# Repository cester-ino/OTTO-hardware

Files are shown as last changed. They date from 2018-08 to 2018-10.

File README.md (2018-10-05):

## OTTO-project
Hardware prototype for the [OTTO Synthesizer by Topisani](https://github.com/topisani/OTTO "OTTO Synthesizer by Topisani")

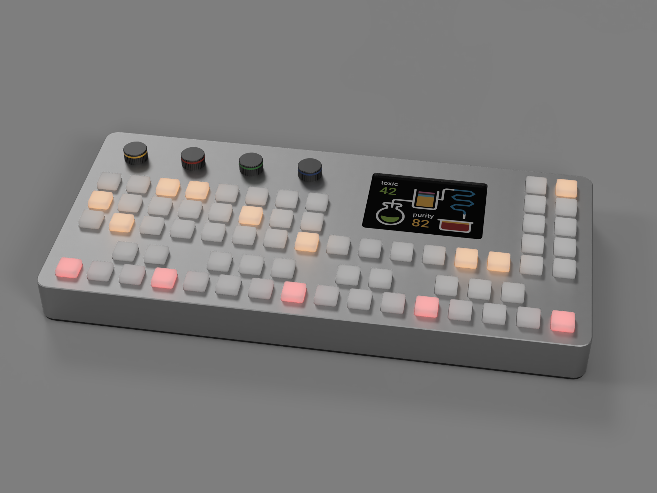
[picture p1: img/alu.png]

*10x10 silicone buttons with led backlight*

Main features

#### Mainboard
- ILI9341 based TFT 2.8" TFT screen.
- 4 low profile clickable encoders
- 40 function keys
- STM32F103VET6 mcu
- Raspberry GPIO connector
- connects to all the various boards
- expansion headers

#### Power board
- 2A 5-16V DC input & 500mah micro usb input
- [MAX8903A](https://datasheets.maximintegrated.com/en/ds/MAX8903-MAX8903Y.pdf "MAX8903A") 1s Lipo charger IC with path management
- 5V 2A DC-DC boost converter ([TPS61090](http://www.ti.com/lit/ds/symlink/tps61090.pdf "TPS61090")) & 3V3 700mah LDO ([XC6210](https://www.torexsemi.com/file/xc6210/XC6210.pdf "XC6210"))
- [MAX17048](https://datasheets.maximintegrated.com/en/ds/MAX17048-MAX17049.pdf "MAX17048") 1s lipo fuel gauge, connected via i2c to the raspberry
- [pi_power](https://github.com/craic/pi_power "pi_power") circuit for monitoring and control boot and shutdown routine

#### Audio Board
- SGTL5000 Audio Codec
- Electret microphone amp circuit
- LM4860 speaker amplifier
- 1 TRS jack line IN
- 1 TRS jack line OUT
- 1 Headphone IN

#### Keyboard
- 2 octaves keyboard with 16 keys bottom row
- expansion headers
- 16 addressable rgb leds

those specs refer to the tactile buttons version, but a led backlight button version is in the works too.

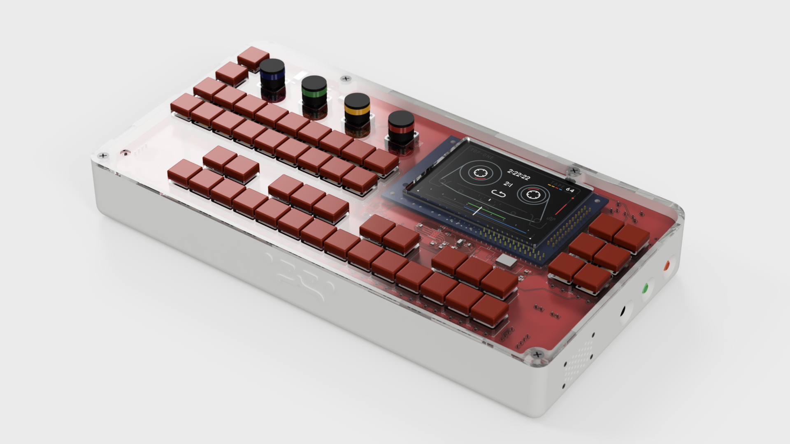
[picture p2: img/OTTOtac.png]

*one of the first design iteration*

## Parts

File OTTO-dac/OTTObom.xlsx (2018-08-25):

Refs | Value | Footprint | Quantity | MFR | MPN | SPR | SPN | Column1
SW55 | ON_OFF_SWITCH | Button_Switch_THT:SK-12E12-G5 | 1 |  |  | lcsc | C136720
SW8;SW7;SW11;SW12;SW15;SW19;SW23;SW27;SW30;SW34;SW36;SW37;SW39;SW43;SW47;SW50;SW18;SW22;SW26;SW33;SW35;SW38;SW42;SW46;SW3;SW4;SW2;SW1;SW5;SW6;SW10;SW14;SW17;SW9;SW13;SW16;SW49;SW45;SW41;SW40;SW44;SW48;SW31;SW28;SW24;SW29;SW25;SW21;SW20;SW32 | SW_Push | Button_Switch_THT:Tactile_Switch_12x12x7.3_mm | 50 | - | - | lcsc | -
MK1 | Microphone | CMA-4544PF-W:CMA-4544PF-W | 1 | - | - | lcsc | C241681 (https://lcsc.com/product-detail/Others_INGHAi-GMI9750UP-2C44DB_C241681.html)
C22 | 0.01uF | Capacitor_SMD:C_0805_2012Metric | 1 | - | - | lcsc | C83170 (https://lcsc.com/product-detail/Multilayer-Ceramic-Capacitors-MLCC-SMD-SMT_10nF-103-10-50V_C83170.html)
C7;C11;C8;C9;C10;C13;C1;C6;C5;C21 | 0.1uF | Capacitor_SMD:C_0805_2012Metric | 10 | - | - | lcsc | C29926 (https://lcsc.com/product-detail/Multilayer-Ceramic-Capacitors-MLCC-SMD-SMT_100nF-104-5-50V_C29926.html) | V
C24 | 100pF | Capacitor_SMD:C_0805_2012Metric | 1 | - | - | lcsc | C107140 (https://lcsc.com/product-detail/Multilayer-Ceramic-Capacitors-MLCC-SMD-SMT_100pF-101-10-50V_C107140.html)
C12 | 10uF | Capacitor_SMD:C_0805_2012Metric | 1 | - | - | lcsc | C48181 (https://lcsc.com/product-detail/Multilayer-Ceramic-Capacitors-MLCC-SMD-SMT_10uF-106-20-25V_C48181.html)
C2;C23 | 1uF | Capacitor_SMD:C_0805_2012Metric | 2 | - | - | lcsc | C89378 (https://lcsc.com/product-detail/Multilayer-Ceramic-Capacitors-MLCC-SMD-SMT_1uF-105-20-25V_C89378.html)
C3;C4 | 22pF | Capacitor_SMD:C_0805_2012Metric | 2 | - | - | lcsc | C38143 (https://lcsc.com/product-detail/Multilayer-Ceramic-Capacitors-MLCC-SMD-SMT_22pF-220-5-50V_C38143.html)
C14 | 22uF | Capacitor_SMD:C_0805_2012Metric | 1 | - | - | lcsc | C89572 (https://lcsc.com/product-detail/Multilayer-Ceramic-Capacitors-MLCC-SMD-SMT_22uF-226-20-10V_C89572.html)
C19;C20 | 0.1uf | Capacitor_Tantalum_SMD:CP_EIA-2012-12_Kemet-R | 2 | - | - | lcsc | C154088
C18 | 1uf | Capacitor_Tantalum_SMD:CP_EIA-2012-12_Kemet-R | 1 | - | - | lcsc | C116269 (https://lcsc.com/product-detail/Tantalum-Capacitors_KEMET_T491A105K016AT_1uF-105-10-16V_C116269.html)
C16;C17 | 220uf | Capacitor_Tantalum_SMD:CP_EIA-2012-12_Kemet-R | 2 | - | - | lcsc | C7200
C15 | 22uF | Capacitor_Tantalum_SMD:CP_EIA-2012-12_Kemet-R | 1 | - | - | lcsc | C117031 (https://lcsc.com/product-detail/Tantalum-Capacitors_KEMET_T491B226M010AT_22uF-226-20-10V_C117031.html)
J10 | Conn_01x04_Male | Connector_JST:JST_SH_SM04B-SRSS-TB_1x04-1MP_P1.00mm_Horizontal | 1 | - | - | lcsc | C160404
J6 | Speaker | Connector_JST:JST_XH_B02B-XH-A_1x02_P2.50mm_Vertical | 1 | JST | XH-B02B | lcsc | C20079 (https://lcsc.com/product-detail/XH-Connectors_XH-2A-2P-pitch2-5mm-Straight-line_C20079.html)
J3 | battery | Connector_JST:JST_XH_B02B-XH-A_1x02_P2.50mm_Vertical | 1 | JST | XH-B02B | lcsc | C20079 (https://lcsc.com/product-detail/XH-Connectors_XH-2A-2P-pitch2-5mm-Straight-line_C20079.html)
J1 | USB | Connector_PinHeader_2.54mm:PinHeader_1x04_P2.54mm_Vertical | 1 | - | 1x04 pin header | lcsc | C124378 (https://lcsc.com/product-detail/Male-Header_Shenzhen-Cancome-Headers-Pins-1-4P-2-54mm-Straight-line_C124378.html)
J4 | audio | Connector_PinHeader_2.54mm:PinHeader_1x04_P2.54mm_Vertical | 1 | - | 1x04 pin header | lcsc | C124378 (https://lcsc.com/product-detail/Male-Header_Shenzhen-Cancome-Headers-Pins-1-4P-2-54mm-Straight-line_C124378.html)
J8 | gpio_exp1 | Connector_PinHeader_2.54mm:PinHeader_2x20_P2.54mm_Vertical | 1 | 2x20 long pin header | - | lcsc | C124383 (https://lcsc.com/product-detail/Male-Header_Shenzhen-Cancome-Headers-Pins-2-20P-2-54mm-Straight-line_C124383.html)
J7 | gpio_exp2 | Connector_PinHeader_2.54mm:PinHeader_2x20_P2.54mm_Vertical | 1 | 2x20 pin header | - | lcsc | C124383 (https://lcsc.com/product-detail/Male-Header_Shenzhen-Cancome-Headers-Pins-2-20P-2-54mm-Straight-line_C124383.html)
J2 | USB_B_Micro | Connector_USB:USB_Micro-B_Molex-105017-0001 | 1 | Molex | 105017-0001 | lcsc | C136000 (https://lcsc.com/product-detail/Micro-USB-Connectors_MOLEX_105017-0001_105017-0001_C136000.html)
Y1 | 16mhz | Crystal:Crystal_SMD_Abracon_ABM3-2Pin_5.0x3.2mm | 1 | - | ABM3-16.000MHZ-D2Y-T | lcsc | C112572 (https://lcsc.com/product-detail/SMD-Crystals_YSX530GA-16MHZ-20PF-10PPM-40-85_C112572.html)
D58 | SS34 | Diode_SMD:D_SMC | 1 | - | SS34 | lcsc | C13763 (https://lcsc.com/product-detail/Schottky-Barrier-Diodes-SBD_Jiangsu-Yutai-Elec-SS34_C13763.html)
D9;D8;D12;D13;D16;D20;D24;D28;D31;D35;D37;D38;D40;D44;D48;D51;D19;D23;D27;D34;D36;D39;D43;D47;D4;D5;D3;D2;D6;D7;D11;D15;D18;D10;D14;D17;D50;D46;D42;D41;D45;D49;D32;D29;D25;D30;D26;D22;D21;D33;D52;D53;D54;D55 | 1N4148 | Diode_SMD:D_SOD-123v | 54 | - | 1N4148W-E3-18 | lcsc | C129216 (https://lcsc.com/product-detail/Switching-Diode_1N4148W_C129216.html)
U7 | TJCTM24028-SPI | Display:TJCTM24028-SPI | 1 | - | - | lcsc | -
L1 | 22uH | Inductor_SMD:L_7.3x7.3_H4.5 | 1 | Epcos |  | lcsc | C181754
D1 | LED | LED_SMD:LED_0805_2012Metric | 1 | - | HSMW-C170-U0000 | lcsc | C34499 (https://lcsc.com/product-detail/Light-Emitting-Diodes-LED_white-0805_C34499.html)
D57 | LEDG | LED_SMD:LED_0805_2012Metric | 1 | - | HSMQ-C170-T0000 | lcsc | C74344 (https://lcsc.com/product-detail/Light-Emitting-Diodes-LED_0805_C74344.html)
D56 | LEDR | LED_SMD:LED_0805_2012Metric | 1 | - | HSMC-C170-T0000 | lcsc | C131250 (https://lcsc.com/product-detail/Infrared-IR-LEDs_Everlight-Elec-IR17-21C-TR8_C131250.html)
D59;D60;D61;D62;D63 | LED | LED_SMD:LED_0805_2012Metric | 5 | - | HSMW-C170-U0000 | lcsc | C34499 (https://lcsc.com/product-detail/Light-Emitting-Diodes-LED_white-0805_C34499.html)
IC2 | LM3914 | Package_LCC:PLCC-20 | 1 | - | LM3914VX/NOPB | lcsc | C9408 (https://lcsc.com/product-detail/LED-Drivers_TI_LM3914N-1-NOPB_LM3914N-1-NOPB_C9408.html)
U1 | ATMEGA32U4-AU | Package_QFP:TQFP-44-1EP_10x10mm_P0.8mm_EP4.5x4.5mm | 1 | - | ATMEGA32U4-AU | lcsc | 556-ATMEGA32U4-AU
IC1 | 74HC125 | Package_SO:SOIC-14_3.9x8.7mm_P1.27mm | 1 | - | SN74HC125DR | lcsc | 595-SN74HC125DR
U6 | LM4860 | Package_SO:SOIC-16_3.9x9.9mm_P1.27mm | 1 | - | LM4860MX/NOPB | lcsc | -
U2 | MCP602 | Package_SO:SOIC-8_3.9x4.9mm_P1.27mm | 1 | - | MCP6022T-I/SN | lcsc | -
U3 | TP4056 | Package_SO:Texas_HTSOP-8-1EP_3.9x4.9mm_P1.27mm_EP2.95x4.9mm_Mask2.4x3.1mm_ThermalVias | 1 | - | TP4056 SOP-8 | lcsc | C16581 (https://lcsc.com/product-detail/PMIC-Battery-Management_TP4056_C16581.html)
U4 | FS312F-G | Package_TO_SOT_SMD:SOT-23-6 | 1 | - | FS312F-G SOT-23 | lcsc | C82736 (https://lcsc.com/product-detail/Battery-Protection-ICs_FS312F-G_C82736.html)
U5 | MT3608 | Package_TO_SOT_SMD:SOT-23-6 | 1 | - | MT3608 SOT-23 | lcsc | C84817 (https://lcsc.com/product-detail/DC-DC-Converters_MT3608_C84817.html)
M1 | FS8205 | Package_TO_SOT_SMD:SOT-23-6_Handsoldering | 1 | - | FS8205 SOT-23 | lcsc | C94488 (https://lcsc.com/product-detail/MOSFET_RU8205C6_C94488.html)
U8 | MAX4466 | Package_TO_SOT_SMD:SOT-353_SC-70-5 | 1 | - | - | lcsc | -
Q1 | 2N7000 | Package_TO_SOT_THT:TO-92_Inline | 1 | - | - | lcsc | C232838
RV1 | 10K | Potentiometer_SMD:Potentiometer_Vishay_TS53YJ_Vertical | 1 | - | TS53YJ103MR10 | lcsc | C118956 (https://lcsc.com/product-detail/Precision-Potentiometer_10KR_C118956.html)
R15;R13 | 1.5K | Resistor_SMD:R_0805_2012Metric | 2 | - | - | lcsc | C114737 (https://lcsc.com/product-detail/Chip-Resistor-Surface-Mount_1-5KR-152-5_C114737.html) | V
R23;R31;R32;R35;R41 | 100K | Resistor_SMD:R_0805_2012Metric | 5 | - | - | lcsc | C96346 (https://lcsc.com/product-detail/Chip-Resistor-Surface-Mount_100KR-1003-1_C96346.html) | V
R1;R8;R3;R12;R7;R9;R4;R10;R5;R11;R6;R33;R34 | 10K | Resistor_SMD:R_0805_2012Metric | 13 | - | - | lcsc | C101926 (https://lcsc.com/product-detail/Chip-Resistor-Surface-Mount_10KR-103-5_C101926.html) | V
R18 | 15K | Resistor_SMD:R_0805_2012Metric | 1 | - | - | lcsc | C114559 (https://lcsc.com/product-detail/Chip-Resistor-Surface-Mount_15KR-1502-1_C114559.html) | V
R17;R19;R21;R20;R26;R30;R29;R28;R40;R38;R36 | 1K | Resistor_SMD:R_0805_2012Metric | 11 | - | - | lcsc | C100046 (https://lcsc.com/product-detail/Chip-Resistor-Surface-Mount_1KR-102-5_C100046.html) | V
R39;R37 | 1M | Resistor_SMD:R_0805_2012Metric | 2 | - | - | lcsc | C107700 (https://lcsc.com/product-detail/Chip-Resistor-Surface-Mount_1MR-1004-1_C107700.html) | V
R24 | 2.7k | Resistor_SMD:R_0805_2012Metric | 1 | - | - | lcsc | C137454 | V
R22 | 2k | Resistor_SMD:R_0805_2012Metric | 1 | - | - | lcsc | C114748 (https://lcsc.com/product-detail/Chip-Resistor-Surface-Mount_2KR-202-5_C114748.html) | V
R2 | 330K | Resistor_SMD:R_0805_2012Metric | 1 | - | - | lcsc | C114528 (https://lcsc.com/product-detail/Chip-Resistor-Surface-Mount_330KR-3303-1_C114528.html) | V
R27 | 4.7K | Resistor_SMD:R_0805_2012Metric | 1 | - | - | lcsc | C60816 (https://lcsc.com/product-detail/Chip-Resistor-Surface-Mount_4-7K-4701-1_C60816.html) | V
R14 | 470K | Resistor_SMD:R_0805_2012Metric | 1 | - | - | lcsc | C104346 (https://lcsc.com/product-detail/Chip-Resistor-Surface-Mount_470KR-4703-1_C104346.html) | V
R25 | 7.5K | Resistor_SMD:R_0805_2012Metric | 1 | - | - | lcsc | C114547 (https://lcsc.com/product-detail/Chip-Resistor-Surface-Mount_7-5KR-7501-1_C114547.html) | V
R16 | 820K | Resistor_SMD:R_0805_2012Metric | 1 | - | - | lcsc | C141700 | V
SW51;SW52;SW53;SW54 | Rotary_Encoder_Switch | Rotary_Encoder:RotaryEncoder_Alps_EC12E-Switch_Vertical_H20mm_CircularMountingHoles | 4 | - |  | lcsc | C202365
J5 | SJ1-42536-SMT | SJ1:CUI_SJ1-42536-SMT | 1 | Cui | SJ1-42536-SMT | lcsc | C128992

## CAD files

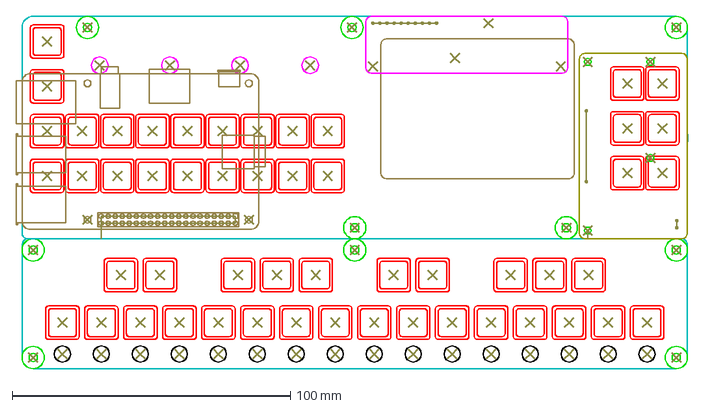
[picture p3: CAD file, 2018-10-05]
OTTO_align.dxf
241.0 x 126.6 mm

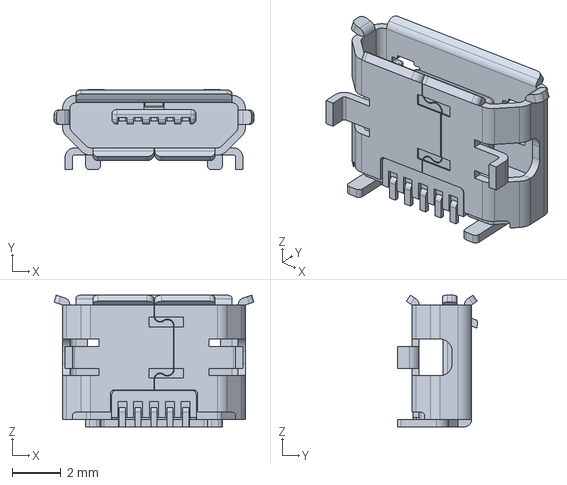
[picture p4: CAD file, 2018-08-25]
1050170001.stp
8.20 x 3.30 x 5.40 mm

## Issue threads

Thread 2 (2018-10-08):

Main Board review

cester-ino, 2018-10-08:
- [ ] Add the midi/cv board connector
- [ ] Optimize ground and 5V planes
- [ ] check board routing

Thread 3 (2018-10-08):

Audio Board review:

cester-ino, 2018-10-08:
- [ ] component footprint and values (with a special attention to the caps)
- [ ] board routing (GND & AGND planes)

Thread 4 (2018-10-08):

Power Board review:

cester-ino, 2018-10-08:
- [ ] check if the reset and the pi_power logic works
- [ ] component footprint and values
- [ ] board routing

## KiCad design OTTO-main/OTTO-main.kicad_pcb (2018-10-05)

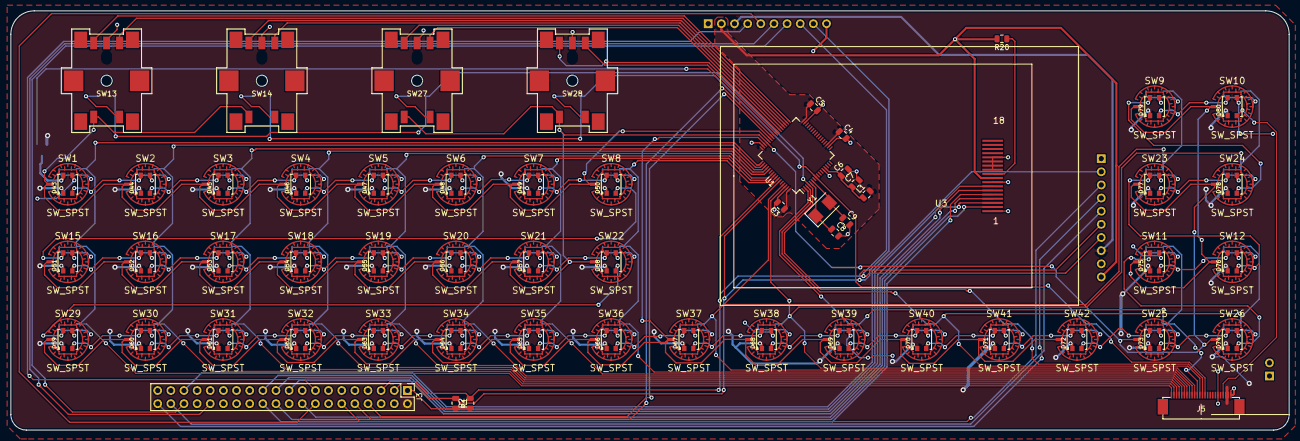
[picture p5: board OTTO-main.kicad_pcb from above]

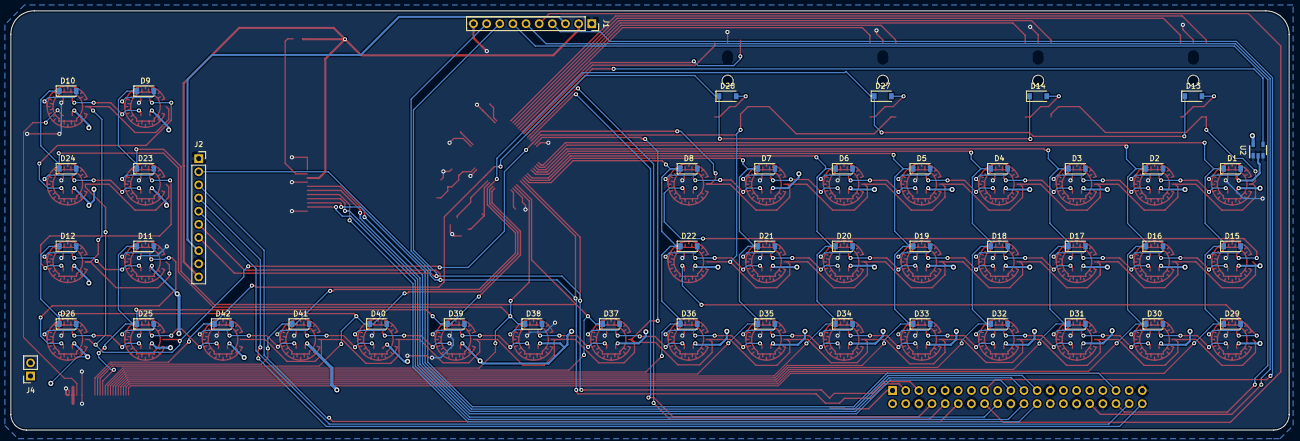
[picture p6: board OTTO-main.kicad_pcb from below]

Board: 4 copper layers, 247.0 x 81.0 mm, 142 parts (46 on the bottom side), 133 nets.

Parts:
C3, C4, C5, C6: 1uf; C_0805_2012Metric
C7: 10nf; C_0805_2012Metric
C8, C9: 22pf; C_0805_2012Metric
D1, D2, D3, D4, D5, D6, D7, D8, D9, D10, D11, D12, D15, D16, D17, D18, D19, D20, D21, D22, D23, D24, D25, D26, D29, D30, D31, D32, D33, D34, D35, D36, D37, D38, D39, D40, D41, D42: D_ALT; D_SOD-123
D13, D14, D27, D28: 1N4148; D_SOD-123
D43, D44, D45, D46, D47, D48, D49, D50, D51, D52, D53, D54, D55, D56, D57, D58, D59, D60, D61, D62, D63, D64, D65, D66, D67, D68, D69, D70, D71, D72, D73, D74, D75, D76, D77, D78, D79, D80: WS2812B; WS2812B_3535
J1: POWER_BOARD; PinSocket_1x10_P2.54mm_Vertical
J2: AUDIO_BOARD; PinSocket_1x10_P2.54mm_Vertical
J3: Raspberry_Pi_2_3; PinHeader_2x20_P2.54mm_Vertical
J4: MICROPHONE; PinSocket_1x02_P2.54mm_Vertical
J5: Conn_01x24; JUSHUO_AFC07-S24FCC-00
L1: 30ohm; C_0805_2012Metric
R1, R2: 4.7K; R_0805_2012Metric
R20: 3.9; R_0805_2012Metric
SW1, SW2, SW3, SW4, SW5, SW6, SW7, SW8, SW9, SW10, SW11, SW12, SW15, SW16, SW17, SW18, SW19, SW20, SW21, SW22, SW23, SW24, SW25, SW26, SW29, SW30, SW31, SW32, SW33, SW34, SW35, SW36, SW37, SW38, SW39, SW40, SW41, SW42: SW_SPST; SILICONE_BUTTON_10MM_4X4WIDE
SW13, SW14, SW27, SW28: Rotary_Encoder_Switch; PEC11S-929K-S0015
U1: STM32F103RETx; LQFP-64_10x10mm_P0.5mm
U2: 74AHCT1G125; SOT-23-5
U3: ILI9341; ILI_DISPLAY
Y1: 8mhz; Crystal_SMD_5032-2Pin_5.0x3.2mm

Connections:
3V3: C3.1, C4.1, C5.1, J1.2, J2.10, L1.2, R20.2, U1.19, U1.32, U1.48, U1.64, U3.9
5V: D43.1, D44.1, D45.1, D46.1, D47.1, D48.1, D49.1, D50.1, D51.1, D52.1, D53.1, D54.1, D55.1, D56.1, D57.1, D58.1, D59.1, D60.1, D61.1, D62.1, D63.1, D64.1, D65.1, D66.1, D67.1, D68.1, D69.1, D70.1, D71.1, D72.1, D73.1, D74.1, D75.1, D76.1, D77.1, D78.1, D79.1, D80.1, J1.3, J2.8, J3.2, J5.22, J5.23, U2.5
BCLK: J2.3, J3.12
CE0: J3.24, U3.5
CHG_OUT: J1.7, J3.36
COL1: D1.1, D15.1, D29.1, J5.1, U1.49
COL2: D2.1, D16.1, D30.1, J5.2, U1.50
COL3: D3.1, D17.1, D31.1, J5.3, U1.51
COL4: D4.1, D18.1, D32.1, J5.4, U1.52
COL5: D5.1, D19.1, D33.1, J5.5, U1.53
COL6: D6.1, D20.1, D34.1, J5.6, U1.55
COL7: D7.1, D21.1, D35.1, J5.7, U1.56
COL8: D8.1, D22.1, D36.1, J5.8, U1.57
COL9: D9.1, D23.1, D37.1, J5.9, U1.61
COL10: D10.1, D24.1, D38.1, J5.10, U1.62
COL11: D11.1, D25.1, D39.1, J5.11, U1.2
COL12: D12.1, D26.1, D40.1, J5.12, U1.3
COL13: D13.1, D27.1, D41.1, J5.13, U1.4
COL14: D14.1, D28.1, D42.1, J5.14, U1.8
DOK_OUT: J1.6, J3.32
DOUT1: D52.2, D53.4
DOUT2: D66.2, D67.4
ENC1_A: SW13.A, U1.34
ENC1_B: SW13.B, U1.33
ENC2_A: SW14.A, U1.36
ENC2_B: SW14.B, U1.35
ENC3_A: SW27.A, U1.38
ENC3_B: SW27.B, U1.37
ENC4_A: SW28.A, U1.40
ENC4_B: SW28.B, U1.39
GND: C3.2, C4.2, C5.2, C6.2, C7.2, C8.2, C9.2, D43.3, D44.3, D45.3, D46.3, D47.3, D48.3, D49.3, D50.3, D51.3, D52.3, D53.3, D54.3, D55.3, D56.3, D57.3, D58.3, D59.3, D60.3, D61.3, D62.3, D63.3, D64.3, D65.3, D66.3, D67.3, D68.3, D69.3, D70.3, D71.3, D72.3, D73.3, D74.3, D75.3, D76.3, D77.3, D78.3, D79.3, D80.3, J1.1, J1.10, J2.1, J2.9, J3.6, J3.9, J3.14, J3.20, J3.25, J3.30, J3.34, J3.39, J5.19, J5.24, SW13.C, SW14.C, SW27.C, SW28.C, U1.12, U1.18, U1.31, U1.47, U1.63, U2.1, U2.3, U3.1, U3.8, U3.11, U3.12, U3.13, U3.14
GPIO24: J3.18, U3.4
GPIO25: J3.22, U3.2
I2S_RX: J2.4, J3.40
I2S_TX: J2.5, J3.38
KBLED: D80.2, J5.21
LEDIN: U1.41, U2.4
LR_CLK: J2.2, J3.35
MISO_0: J3.21, U3.7
MOSI_0: J3.19, U3.6
unnamed: C6.1, C7.1, L1.1, U1.13
unnamed: D1.2, SW1.2
unnamed: D2.2, SW2.2
unnamed: D3.2, SW3.2
unnamed: D4.2, SW4.2
unnamed: D5.2, SW5.2
unnamed: D6.2, SW6.2
unnamed: D7.2, SW7.2
unnamed: D8.2, SW8.2
unnamed: D9.2, SW9.2
unnamed: D10.2, SW10.2
unnamed: D11.2, SW11.2
unnamed: D12.2, SW12.2
unnamed: D13.2, SW13.S1
unnamed: D14.2, SW14.S1
unnamed: D15.2, SW15.2
unnamed: D16.2, SW16.2
unnamed: D17.2, SW17.2
unnamed: D18.2, SW18.2
unnamed: D19.2, SW19.2
unnamed: D20.2, SW20.2
unnamed: D21.2, SW21.2
unnamed: D22.2, SW22.2
unnamed: D23.2, SW23.2
unnamed: D24.2, SW24.2
unnamed: D25.2, SW25.2
unnamed: D26.2, SW26.2
unnamed: D27.2, SW27.S1
unnamed: D28.2, SW28.S1
unnamed: D29.2, SW29.2
unnamed: D30.2, SW30.2
unnamed: D31.2, SW31.2
unnamed: D32.2, SW32.2
unnamed: D33.2, SW33.2
unnamed: D34.2, SW34.2
unnamed: D35.2, SW35.2
unnamed: D36.2, SW36.2
unnamed: D37.2, SW37.2
unnamed: D38.2, SW38.2
unnamed: D39.2, SW39.2
unnamed: D40.2, SW40.2
unnamed: D41.2, SW41.2
unnamed: D42.2, SW42.2
unnamed: D43.2, D44.4
unnamed: D43.4, U2.2
unnamed: D44.2, D45.4
unnamed: D45.2, D46.4
unnamed: D46.2, D47.4
unnamed: D47.2, D48.4
unnamed: D48.2, D49.4
unnamed: D49.2, D50.4
unnamed: D50.2, D51.4
unnamed: D51.2, D52.4
unnamed: D53.2, D54.4
unnamed: D54.2, D55.4
unnamed: D55.2, D56.4
unnamed: D56.2, D57.4
unnamed: D57.2, D58.4
unnamed: D58.2, D59.4
unnamed: D59.2, D60.4
unnamed: D60.2, D61.4
unnamed: D61.2, D62.4
unnamed: D62.2, D63.4
unnamed: D63.2, D64.4
unnamed: D64.2, D65.4
unnamed: D65.2, D66.4
unnamed: D67.2, D68.4
unnamed: D68.2, D69.4
unnamed: D69.2, D70.4
unnamed: D70.2, D71.4
unnamed: D71.2, D72.4
unnamed: D72.2, D73.4
unnamed: D73.2, D74.4
unnamed: D74.2, D75.4
unnamed: D75.2, D76.4
unnamed: D76.2, D77.4
unnamed: D77.2, D78.4
unnamed: D78.2, D79.4
unnamed: D79.2, D80.4
unnamed: J3.1, R1.2, R2.1
unnamed: R20.1, U3.10
OSC_IN: C8.1, U1.5, Y1.1
OSC_OUT: C9.1, U1.6, Y1.2
OUT_PIN: J1.4, J3.15
ROW1: SW1.1, SW2.1, SW3.1, SW4.1, SW5.1, SW6.1, SW7.1, SW8.1, SW9.1, SW10.1, SW11.1, SW12.1, SW13.S2, SW14.S2, U1.44
ROW2: SW15.1, SW16.1, SW17.1, SW18.1, SW19.1, SW20.1, SW21.1, SW22.1, SW23.1, SW24.1, SW25.1, SW26.1, SW27.S2, SW28.S2, U1.45
ROW3: SW29.1, SW30.1, SW31.1, SW32.1, SW33.1, SW34.1, SW35.1, SW36.1, SW37.1, SW38.1, SW39.1, SW40.1, SW41.1, SW42.1, U1.46
SCL: J1.8, J2.7, J3.5, R2.2, U1.58
SCLK_0: J3.23, U3.3
SDA: J1.9, J2.6, J3.3, R1.1, U1.59
SENSE_PIN: J1.5, J3.16
UART_RXD: J3.10, U1.42
UART_TXD: J3.8, U1.43

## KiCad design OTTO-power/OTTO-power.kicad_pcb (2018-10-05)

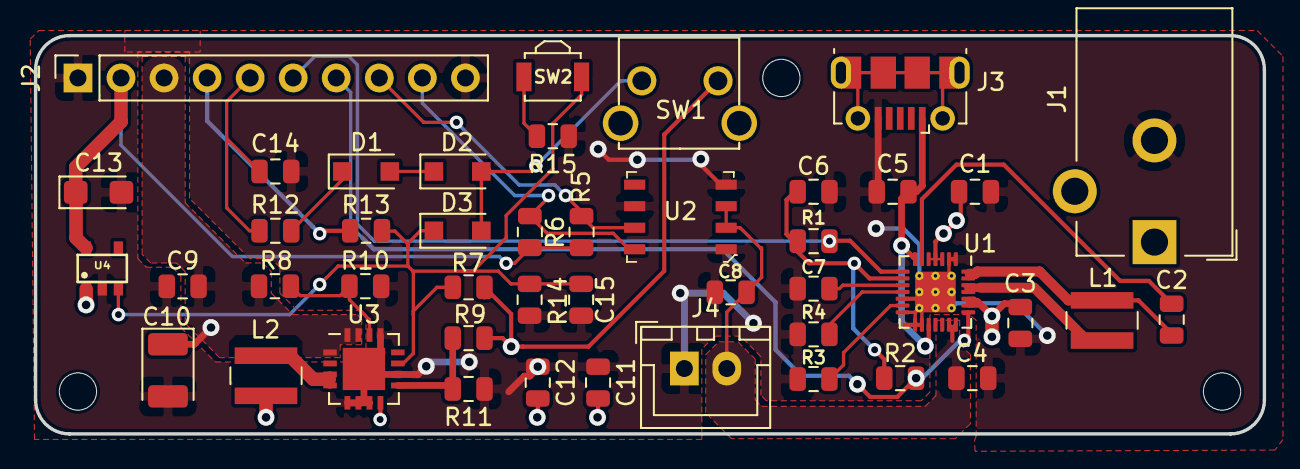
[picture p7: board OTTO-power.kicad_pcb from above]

Board: 2 copper layers, 72.5 x 23.5 mm, 45 parts (0 on the bottom side), 28 nets.

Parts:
C1, C6, C9: 2.2uf; C_0805_2012Metric
C2: 1uf; C_0805_2012Metric
C3, C4, C11: 10uf; C_0805_2012Metric
C5: 4.7uf; C_0805_2012Metric
C7: 0.15uf; C_0805_2012Metric
C8, C12, C14: 0.1uf; C_0805_2012Metric
C10: 100uf; CP_EIA-3528-21_Kemet-B
C13: 10uf; CP_EIA-3216-18_Kemet-A
C15: 100uf; C_0805_2012Metric
D1, D2, D3: IN4001; D_SOD-123F
J1: Barrel_Jack; BarrelJack_CUI_PJ-102AH_Horizontal
J2: Conn_01x10; PinSocket_1x10_P2.54mm_Vertical
J3: USB_B_Micro; USB_Micro-B_Molex-105017-0001
J4: battery; JST_XH_B02B-XH-A_1x02_P2.50mm_Vertical
L1: 3.3uH; L_Wuerth_MAPI-4020
L2: 6.8uH; L_Wuerth_MAPI-4020
R1, R2, R5, R6, R14: 100K; R_0805_2012Metric
R3: 1.2K; R_0805_2012Metric
R4: 3K; R_0805_2012Metric
R7, R10: 200K; R_0805_2012Metric
R8, R9: 1.87M; R_0805_2012Metric
R11: 340K; R_0805_2012Metric
R12, R13: 10K; R_0805_2012Metric
R15: 1K; R_0805_2012Metric
SW1: SW_Push; SKHHLVA010
SW2: SW_reset; SW_SPST_B3U-3000P
U1: MAX8903A; QFN-28-1EP_4x4mm_P0.4mm_EP2.4x2.4mm_ThermalVias
U2: MAX17048; TDFN-8-1EP
U3: TPS61090; QFN-16-1EP_4x4mm_P0.65mm_EP2.5x2.5mm
U4: XC6210; SOT25

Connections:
3V3: C13.1, J2.2, R5.2, R6.2, U4.5
5V: C9.2, C10.1, J2.3, R8.2, U3.1, U3.15, U3.16
BATT+: C4.2, C8.2, J4.2, U1.20, U1.21, U2.2, U2.3
CHG_OUT: J2.7, R2.1, U1.22
DC: C1.1, J1.1, U1.3, U1.4, U1.5
DOK_OUT: J2.6, R1.1, U1.8
EN_PI: C15.1, D3.1, R7.1, R13.1, R14.2, SW2.2, U3.11, U4.3
GNDA: C1.2, C3.1, C4.1, C5.1, C6.1, C7.1, C8.1, C9.1, C10.2, C11.1, C12.1, C13.2, C14.2, C15.2, J1.2, J2.1, J2.10, J3.5, J4.1, R3.1, R4.1, R10.1, R11.1, R14.1, R15.1, U1.1, U1.2, U1.12, U1.14, U1.15, U1.16, U1.29, U2.1, U2.4, U2.6, U3.5, U3.6, U3.7, U3.10, U3.13, U3.17, U4.2
unnamed: C2.1, U1.6
unnamed: C2.2, L1.2, U1.27, U1.28
unnamed: C7.2, U1.10
unnamed: D1.1, R12.1
unnamed: D1.2, D2.1
unnamed: D2.2, D3.2, SW1.2
unnamed: L1.1, U1.25, U1.26
unnamed: L2.1, U3.3, U3.4
unnamed: R3.2, U1.13
unnamed: R4.2, U1.11
unnamed: R8.1, R10.2, U3.14
unnamed: R9.1, R11.2, U3.9
unnamed: R15.2, SW2.1
OUT_PIN: J2.4, R13.2
SCL: J2.8, R5.1, U2.7
SDA: J2.9, R6.1, U2.8
SENSE_PIN: C14.1, J2.5, R12.2
SYS: C3.2, C11.2, C12.2, L2.2, R7.2, R9.2, SW1.1, U1.23, U1.24, U3.8, U4.1
USB: C5.2, J3.1, U1.7, U1.17
VL: C6.2, R1.2, R2.2, U1.9

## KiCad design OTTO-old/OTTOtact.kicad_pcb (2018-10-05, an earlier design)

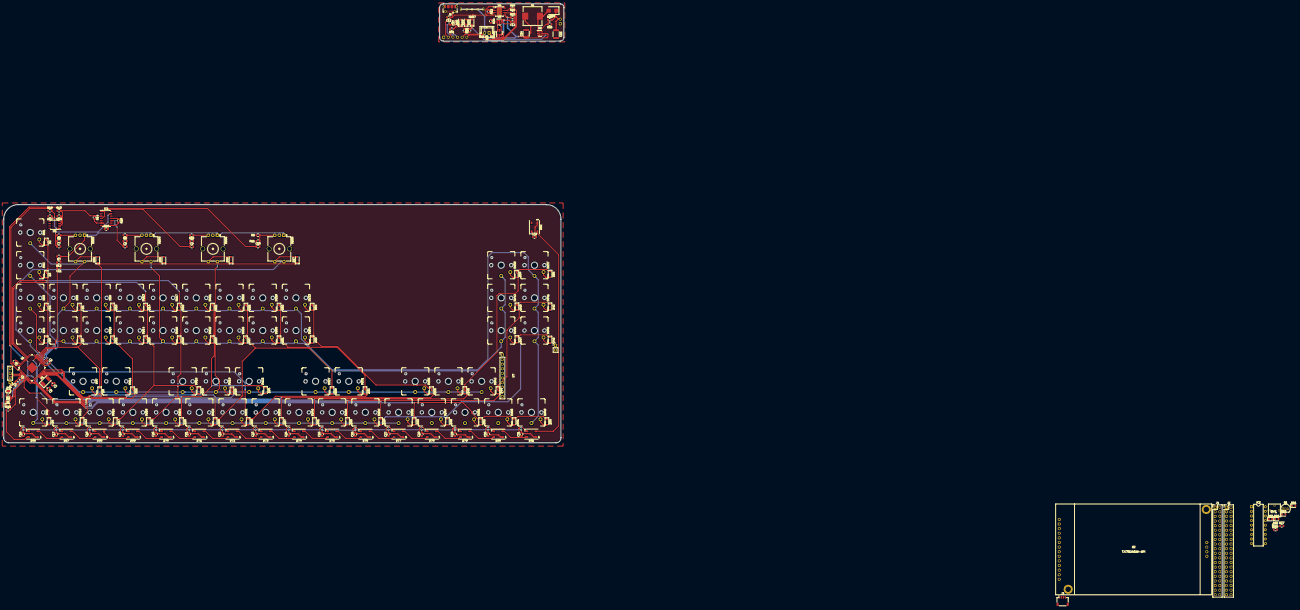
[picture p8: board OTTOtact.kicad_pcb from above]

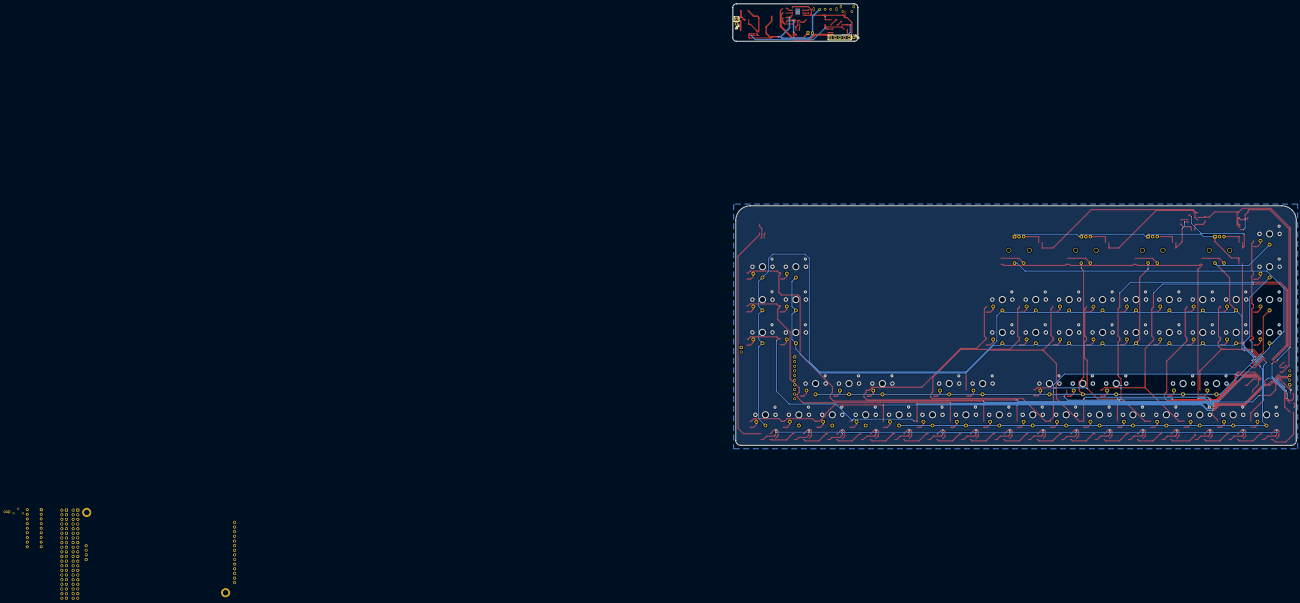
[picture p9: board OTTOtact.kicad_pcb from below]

Board: 2 copper layers, 307.0 x 131.2 mm, 229 parts (2 on the bottom side), 184 nets.

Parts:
C1, C5, C6, C7, C8, C9, C10, C11, C13, C33, C34: 0.1uF; C_0805_2012Metric
C2: 1uF; C_0805_2012Metric
C3, C4: 22pF; C_0805_2012Metric
C12: 10uF; C_0805_2012Metric
C14, C15: 22uF; C_1812_4532Metric
C16, C17, C18, C19, C20, C21, C22, C23, C24, C25, C26, C27, C28, C29, C30, C31, C32: 0.1uf; C_0805_2012Metric
D1: LED; LED_0805_2012Metric
D2, D3, D4, D5, D6, D7, D8, D9, D10, D11, D12, D13, D14, D15, D16, D17, D18, D19, D20, D21, D22, D23, D24, D25, D26, D27, D28, D29, D30, D31, D32, D33, D34, D35, D36, D37, D38, D39, D40, D41, D42, D43, D44, D45, D46, D47, D48, D49, D50, D51, D52, D53, D54, D55, D56, D57: 1N4148; D_SOD-123v
D60: SS34; D_SMB
D61, D62, D63, D64, D65: LED_Small; LED_0805_2012Metric
D66, D67, D68, D69, D70, D71, D72, D73, D74, D75, D76, D77, D78, D79, D80, D81, D82: WS2812B; LED_WS2812B_PLCC4_5.0x5.0mm_P3.2mm
D83, D84, D85: IN4001; D_SOD-123F
IC1: 74HC125; SOIC-14_3.9x8.7mm_P1.27mm
IC2: LM3914; DIP-18_W7.62mm
J1: USB; PinHeader_1x04_P2.54mm_Vertical
J2: gpio_exp2; PinHeader_2x20_P2.54mm_Vertical
J3: Conn_01x04_Male; JST_SH_SM04B-SRSS-TB_1x04-1MP_P1.00mm_Horizontal
J4: gpio_exp1; PinHeader_2x20_P2.54mm_Vertical
J5: USB_B_Micro; USB_Micro-B_Molex-105017-0001
J6: battery; JST_XH_B02B-XH-A_1x02_P2.50mm_Vertical
J7: Conn_01x06; PinHeader_1x06_P2.54mm_Vertical
J8: Conn_01x02; PinHeader_1x02_P2.54mm_Vertical
JP1: SolderJumper_2_Open; SolderJumper-2_P1.3mm_Open_RoundedPad1.0x1.5mm
L1: 22uH; L_Wuerth_HCI-1040
M1: FS8205; SOT-23-6_Handsoldering
Q1: 2N7000; TO-92_Inline
R1, R3, R4, R5, R6, R7, R8, R9, R10, R11, R12, R30, R31, R32: 10K; R_0805_2012Metric
R2: 330K; R_0805_2012Metric
R13, R15: 1.5K; R_0805_2012Metric
R14: 470K; R_0805_2012Metric
R16: 820K; R_0805_2012Metric
R17, R19, R20, R21, R26: 1K; R_0805_2012Metric
R18: 15K; R_0805_2012Metric
R22: 2k; R_0805_2012Metric
R23, R28: 100K; R_0805_2012Metric
R24: 2.7k; R_0805_2012Metric
R25: 7.5K; R_0805_2012Metric
R27: 4.7K; R_0805_2012Metric
R29: 330; R_0805_2012Metric
RV1: 10K; 3362P_1
SW1, SW2, SW3, SW4, SW5, SW6, SW7, SW8, SW9, SW10, SW11, SW12, SW13, SW14, SW15, SW16, SW17, SW18, SW19, SW20, SW21, SW22, SW23, SW24, SW25, SW26, SW27, SW28, SW29, SW30, SW31, SW32, SW33, SW34, SW35, SW36, SW37, SW38, SW39, SW40, SW41, SW42, SW43, SW44, SW45, SW46, SW47, SW48, SW49, SW50, SW51, SW52: SW_Push; kaihl-low-profile-switch-noled
SW53, SW54, SW55, SW56: Rotary_Encoder_Switch; RotaryEncoder_Alps_EC12E-Switch_Vertical_H20mm_CircularMoun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
SW57: ON_OFF_SWITCH; SK-12E12-G5
U1: ATMEGA32U4-AU; TQFP-44-1EP_10x10mm_P0.8mm_EP4.5x4.5mm
U2: TJCTM24028-SPI
U3: MCP602; SOIC-8_3.9x4.9mm_P1.27mm
U4: TP4056; Texas_HTSOP-8-1EP_3.9x4.9mm_P1.27mm_EP2.95x4.9mm_Mask2.4x3.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
U5: FS312F-G; SOT-23-6
U6: MT3608; SOT-23-6
U7: OTTO-dac; OTTO_DACv0.1
Y1: 16mhz; Crystal_SMD_Abracon_ABM3-2Pin_5.0x3.2mm

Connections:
5V: C15.1, D60.1, J8.2, R25.2
36: J2.36, J4.36, Q1.2, R28.1
+5V: C1.2, C5.1, C6.2, C16.2, C17.2, C18.2, C19.2, C20.2, C21.2, C22.2, C23.2, C24.2, C25.2, C26.2, C27.2, C28.2, C29.2, C30.2, C31.2, C32.2, D1.2, D66.1, D67.1, D68.1, D69.1, D70.1, D71.1, D72.1, D73.1, D74.1, D75.1, D76.1, D77.1, D78.1, D79.1, D80.1, D81.1, D82.1, IC1.2, IC1.5, IC1.7, IC1.9, IC1.12, J2.2, J4.2, R1.1, R3.2, R4.2, R5.2, R6.2, R7.2, R18.2, U1.2, U1.7, U1.14, U1.24, U1.34, U1.44, U7.8
-BATT: C13.2, J6.1, M1.3, U5.6
/gpio/1: J2.1, J3.2, J4.1, U2.1, U7.10
/gpio/3: J2.3, J3.3, J4.3, U7.6
/gpio/4: J2.4, J4.4
/gpio/5: J2.5, J3.4, J4.5, U7.7
/gpio/7: J2.7, J4.7
/gpio/8: J2.8, J4.8
/gpio/9: J2.9, J4.9
/gpio/11: J2.11, J4.11
/gpio/12: J2.12, J4.12, U2.8, U7.3
/gpio/13: J2.13, J4.13
/gpio/14: J2.14, J4.14
/gpio/15: J2.15, J4.15
/gpio/16: J2.16, J4.16
/gpio/17: J2.17, J4.17
/gpio/18: J2.18, J4.18, U2.5
/gpio/19: J2.19, J4.19, U2.6
/gpio/20: J2.20, J4.20
/gpio/21: J2.21, J4.21, U2.9
/gpio/22: J2.22, J4.22, U2.4
/gpio/23: J2.23, J4.23, U2.7
/gpio/24: J2.24, J4.24, U2.3
/gpio/25: J2.25, J4.25
/gpio/26: J2.26, J4.26
/gpio/27: J2.27, J4.27
/gpio/28: J2.28, J4.28
/gpio/29: J2.29, J4.29
/gpio/30: J2.30, J4.30
/gpio/31: J2.31, J4.31
/gpio/32: J2.32, J4.32
/gpio/33: J2.33, J4.33
/gpio/34: J2.34, J4.34
/gpio/35: J2.35, J4.35, U7.2
/gpio/37: J2.37, J4.37
/gpio/38: J2.38, J4.38, U7.5
/gpio/39: J2.39, J4.39
/gpio/40: J2.40, J4.40, U7.4
BATT: C14.1, D61.2, D62.2, D63.2, D64.2, D65.2, IC2.3, IC2.9, J6.2, L1.1, R23.1, R27.2, SW57.3, U4.5, U6.5
COL1: D2.1, D3.1, D4.1, D5.1, U1.29
COL2: D6.1, D7.1, D8.1, D9.1, U1.31
COL3: D10.1, D11.1, D12.1, D13.1, U1.32
COL4: D14.1, D15.1, D16.1, D17.1, U1.36
COL5: D18.1, D19.1, D20.1, D21.1, U1.37
COL6: D22.1, D23.1, D24.1, D25.1, U1.22
COL7: D26.1, D27.1, D28.1, D29.1, U1.21
COL8: D30.1, D31.1, D32.1, D33.1, U1.20
COL9: D34.1, D35.1, D36.1, D37.1, U1.19
COL10: D38.1, D39.1, D40.1, D41.1, U1.18
COL11: D42.1, D43.1, D44.1, D45.1, U1.12
COL12: D46.1, D47.1, D48.1, D49.1, U1.11
COL13: D50.1, D51.1, D52.1, D53.1, U1.10
COL14: D54.1, D55.1, D56.1, D57.1, U1.9
D+: J1.2, U1.4
D-: J1.3, U1.3
EN: C34.1, D85.1, R31.1, R32.2, U6.4
GNDREF: C1.1, C2.2, C3.2, C4.2, C5.2, C6.1, C7.2, C8.2, C9.2, C10.2, C11.2, C12.2, C14.2, C15.2, C16.1, C17.1, C18.1, C19.1, C20.1, C21.1, C22.1, C23.1, C24.1, C25.1, C26.1, C27.1, C28.1, C29.1, C30.1, C31.1, C32.1, C33.1, C34.2, D66.3, D67.3, D68.3, D69.3, D70.3, D71.3, D72.3, D73.3, D74.3, D75.3, D76.3, D77.3, D78.3, D79.3, D80.3, D81.3, D82.3, IC1.14, J1.1, J2.6, J3.1, J4.6, J5.5, J5.6, J7.1, J8.1, JP1.2, M1.1, Q1.1, R13.1, R17.2, R19.1, R22.2, R24.2, R26.1, R28.2, R32.1, SW53.C, SW54.C, SW55.C, SW56.C, U1.5, U1.15, U1.23, U1.33, U1.35, U1.43, U1.45, U2.2, U4.1, U4.3, U4.9, U6.2, U7.1, U7.9
LED: R29.2, U1.8
LED_G: J7.5, R21.2
LED_POW: C12.1, J5.1, J7.2, U4.4, U4.8
LED_R: J7.6, R20.2
unnamed: C2.1, U1.17, Y1.2
unnamed: C3.1, U1.16, Y1.1
unnamed: C4.1, U1.6
unnamed: C7.1, IC1.13, R8.1
unnamed: C8.1, IC1.10, R9.1
unnamed: C9.1, IC1.4, R10.1
unnamed: C10.1, IC1.1, R11.1
unnamed: C13.1, R23.2, U5.5
unnamed: D1.1, R2.1
unnamed: D2.2, SW1.2
unnamed: D3.2, SW2.2
unnamed: D4.2, SW3.2
unnamed: D5.2, SW4.2
unnamed: D6.2, SW5.2
unnamed: D7.2, SW6.2
unnamed: D8.2, SW7.2
unnamed: D9.2, SW8.2
unnamed: D10.2, SW9.2
unnamed: D11.2, SW10.2
unnamed: D12.2, SW11.2
unnamed: D13.2, SW12.2
unnamed: D14.2, SW13.2
unnamed: D15.2, SW14.2
unnamed: D16.2, SW15.2
unnamed: D17.2, SW16.2
unnamed: D18.2, SW17.2
unnamed: D19.2, SW18.2
unnamed: D20.2, SW19.2
unnamed: D21.2, SW20.2
unnamed: D22.2, SW21.2
unnamed: D23.2, SW22.2
unnamed: D24.2, SW23.2
unnamed: D25.2, SW24.2
unnamed: D26.2, SW25.2
unnamed: D27.2, SW26.2
unnamed: D28.2, SW27.2
unnamed: D29.2, SW28.2
unnamed: D30.2, SW29.2
unnamed: D31.2, SW30.2
unnamed: D32.2, SW31.2
unnamed: D33.2, SW32.2
unnamed: D34.2, SW33.2
unnamed: D35.2, SW34.2
unnamed: D36.2, SW35.2
unnamed: D37.2, SW36.2
unnamed: D38.2, SW37.2
unnamed: D39.2, SW38.2
unnamed: D40.2, SW39.2
unnamed: D41.2, SW40.2
unnamed: D42.2, SW41.2
unnamed: D43.2, SW42.2
unnamed: D44.2, SW43.2
unnamed: D45.2, SW44.2
unnamed: D46.2, SW45.2
unnamed: D47.2, SW46.2
unnamed: D48.2, SW47.2
unnamed: D49.2, SW48.2
unnamed: D50.2, SW49.2
unnamed: D51.2, SW50.2
unnamed: D52.2, SW51.2
unnamed: D53.2, SW52.2
unnamed: D54.2, SW53.S2
unnamed: D55.2, SW54.S2
unnamed: D56.2, SW55.S2
unnamed: D57.2, SW56.S2
unnamed: D60.2, L1.2, U6.1
unnamed: D61.1, IC2.18
unnamed: D62.1, IC2.16
unnamed: D63.1, IC2.14
unnamed: D64.1, IC2.12
unnamed: D65.1, IC2.10
unnamed: D66.2, D67.4
unnamed: D66.4, R29.1
unnamed: D67.2, D68.4
unnamed: D68.2, D69.4
unnamed: D69.2, D70.4
unnamed: D70.2, D71.4
unnamed: D71.2, D72.4
unnamed: D72.2, D73.4
unnamed: D73.2, D74.4
unnamed: D74.2, D75.4
unnamed: D75.2, D76.4
unnamed: D76.2, D77.4
unnamed: D77.2, D78.4
unnamed: D78.2, D79.4
unnamed: D79.2, D80.4
unnamed: D80.2, D81.4
unnamed: D81.2, D82.4
unnamed: D83.1, R30.1
unnamed: D83.2, D84.1
unnamed: D84.2, D85.2, SW57.2
unnamed: IC1.6, R14.2, R16.1
unnamed: IC1.8, R15.2, R16.2
unnamed: IC1.11, R15.1
unnamed: IC2.2, IC2.4, IC2.8, Q1.3, R27.1, RV1.3
unnamed: IC2.5, RV1.2
unnamed: IC2.6, IC2.7, RV1.1
unnamed: M1.4, U5.1
unnamed: M1.6, U5.3
unnamed: R2.2, U1.38
unnamed: R3.1, R8.2, SW53.B
unnamed: R4.1, R9.2, SW54.B
unnamed: R5.1, R10.2, SW55.B
unnamed: R6.1, R11.2, SW56.B
unnamed: R7.1, R12.2, SW53.A, SW54.A, SW55.A, SW56.A
unnamed: R17.1, R18.1, U3.3
unnamed: R20.1, U4.7
unnamed: R21.1, U4.6
unnamed: R22.1, U4.2
unnamed: R24.1, U5.2
unnamed: R25.1, R26.2, U6.3
OUT_PIN: J7.3, R31.2
PD4: C11.1, R12.1, U1.25
PE6: R19.2, U1.1, U3.1
PF4: IC1.3, R13.2, R14.1, U1.39, U3.2
RESET: JP1.1, R1.2, U1.13
ROW1: SW1.1, SW5.1, SW9.1, SW13.1, SW17.1, SW21.1, SW25.1, SW29.1, SW33.1, SW37.1, SW41.1, SW45.1, SW49.1, SW53.S1, U1.30
ROW2: SW2.1, SW6.1, SW10.1, SW14.1, SW18.1, SW22.1, SW26.1, SW30.1, SW34.1, SW38.1, SW42.1, SW46.1, SW50.1, SW54.S1, U1.28
ROW3: SW3.1, SW7.1, SW11.1, SW15.1, SW19.1, SW23.1, SW27.1, SW31.1, SW35.1, SW39.1, SW43.1, SW47.1, SW51.1, SW55.S1, U1.27
ROW4: SW4.1, SW8.1, SW12.1, SW16.1, SW20.1, SW24.1, SW28.1, SW32.1, SW36.1, SW40.1, SW44.1, SW48.1, SW52.1, SW56.S1, U1.26
SENSE_PIN: C33.2, J7.4, R30.2

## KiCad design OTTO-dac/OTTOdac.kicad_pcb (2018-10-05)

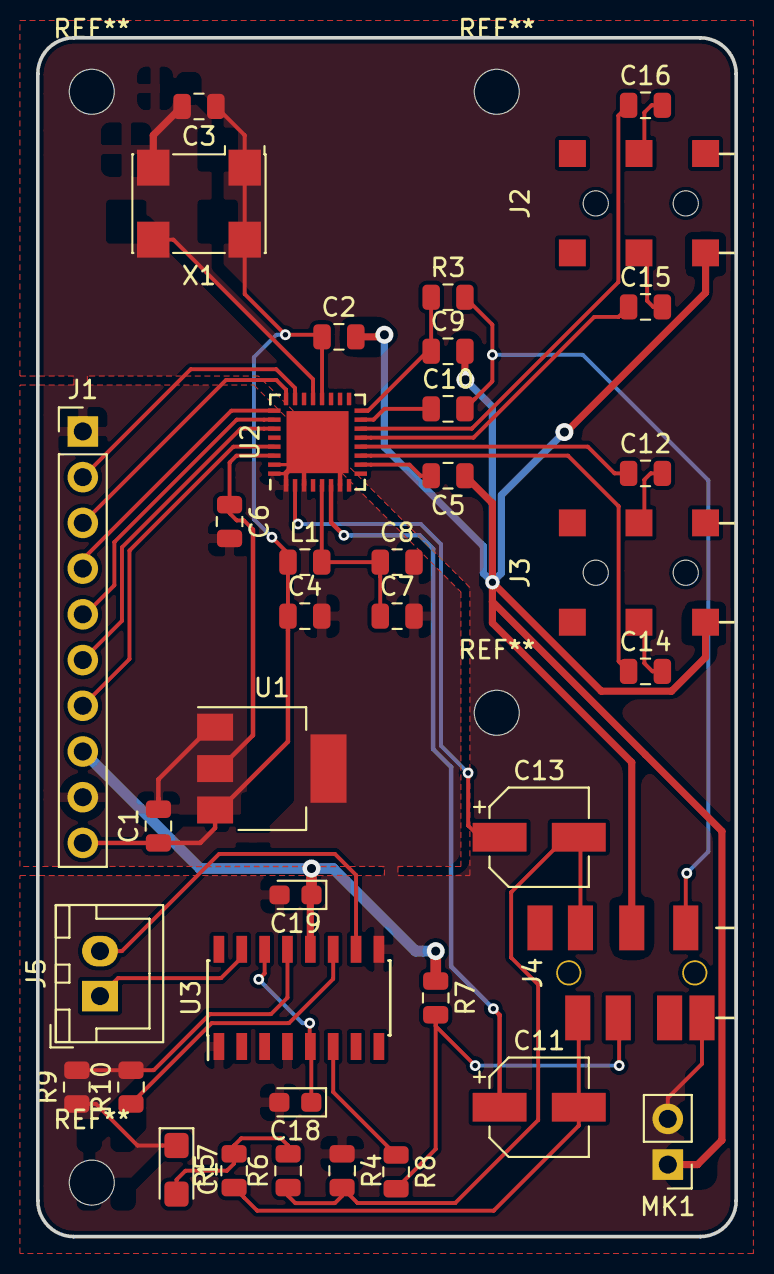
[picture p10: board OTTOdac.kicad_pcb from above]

Board: 2 copper layers, 38.8 x 66.6 mm, 38 parts (0 on the bottom side), 39 nets.

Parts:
C1, C6, C7, C9, C12, C14, C15, C16: 2.2uf; C_0805_2012Metric
C2, C3, C4, C5, C8, C10: 0.1uf; C_0805_2012Metric
C11, C13: 220uf; CP_Elec_5x4.5
C17: 1uf; CP_EIA-3216-18_Kemet-A
C18, C19: 0.1uf; CP_EIA-2012-12_Kemet-R
J1: Conn_01x10; PinHeader_1x10_P2.54mm_Vertical
J2: Audio_IN; PJ-237-6A
J3: Audio_OUT; PJ-237-6A
J4: SJ1-42536-SMT; PJ-393-7A
J5: Speaker; JST_XH_B02B-XH-A_1x02_P2.50mm_Vertical
L1: 600; Fuse_0805_2012Metric
MK1: Microphone; PinHeader_1x02_P2.54mm_Vertical
R3: 2.2K; R_0805_2012Metric
R4, R5, R6: 1K; R_0805_2012Metric
R7, R8: 100K; R_0805_2012Metric
R9, R10: 10K; R_0805_2012Metric
U1: AMS1117-3.3; SOT-223-3_TabPin2
U2: SGTL5000; QFN-32-NXP-SGTL5000
U3: LM4860; SOIC-16_3.9x9.9mm_P1.27mm
X1: XO32; Oscillator_SMD_Abracon_ASV-4Pin_7.0x5.1mm

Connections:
+3V3: C1.1, C2.1, C3.1, C4.1, J1.10, L1.1, U1.3, U2.20, X1.1, X1.4
+5V: C19.1, J1.8, R7.1, U3.12
GNDREF: C1.2, C2.2, C3.2, C4.2, C5.1, C6.2, C7.2, C8.2, C9.2, C18.2, C19.2, J1.1, J1.9, J2.1, J3.1, J4.4, MK1.1, R4.1, U1.1, U2.1, U2.3, U2.7, U2.31, U2.32, U2.33, U3.1, U3.4, U3.9, X1.2
HPL: C11.2, J4.2, R5.1
HPR: C13.2, J4.3, R4.2, R6.1
MIC: C10.2, J4.1, R3.2
unnamed: C5.2, U2.10
unnamed: C6.1, U1.2, U2.30
unnamed: C7.1, C8.1, L1.2, U2.5
unnamed: C9.1, R3.1, U2.16
unnamed: C10.1, U2.15
unnamed: C11.1, U2.6
unnamed: C12.1, U2.12
unnamed: C12.2, J3.2
unnamed: C13.1, U2.2
unnamed: C14.1, U2.11
unnamed: C14.2, J3.3
unnamed: C15.1, U2.13
unnamed: C15.2, J2.3
unnamed: C16.1, U2.14
unnamed: C16.2, J2.2
unnamed: C17.1, R9.1
unnamed: C17.2, R5.2, R6.2
unnamed: C18.1, U3.5, U3.14
unnamed: J4.6, R7.2, R8.2
unnamed: J4.8, MK1.2
unnamed: J5.1, U3.15
unnamed: J5.2, U3.10
unnamed: R8.1, U3.6
unnamed: R10.1, U3.11
unnamed: R9.2, R10.2, U3.13
unnamed: U2.21, X1.3
unnamed: U3.2, U3.3
PIN3: J1.6, U2.27
PIN5: J1.7, U2.29
PIN12: J1.3, U2.24
PIN35: J1.2, U2.23
PIN38: J1.5, U2.26
PIN40: J1.4, U2.25

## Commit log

2018-08-03 readme edit
    [OTTOtact.sch]
2018-08-03 moved USB connector
2018-08-05 redesigned the whole audio amplifier circuit, now the headphone switch should work
    [OTTOtact.sch]
2018-08-07 rewired atmega
    [OTTOtact.sch]
2018-08-10 annotation changes - preliminary BOM added
    [OTTObom.csv, OTTOtact.sch]
2018-08-13 display footprint, bom update
    [CUI_SJ1-42536-SMT-TR.step, OTTObom.csv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]
2018-08-25 0.1v rellease
    [1050170001.stp, OTTObom.csv, OTTObom.xlsx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]
2018-09-24 merged the dev repo with the local
    [1050170001.stp, DAC.sch, OTTO-main.kicad_pcb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]
2018-09-27 added a reset button to the power board
    [OTTO-main.kicad_pcb, OTTO-main.sch, OTTO-power.kicad_pcb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]
2018-09-27 Revert "added a reset button to the power board"
    This reverts commit bbfaa2fb8df27d7f63d1a584e9f51fc8f5fa6fe3.
    [OTTO-main.kicad_pcb, OTTO-main.sch, OTTO-power.kicad_pcb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]
2018-09-27 Revert "Revert "added a reset button to the power board""
    This reverts commit f20825db904c66ff1a5b44b22e19a70ce58abb56.
    [OTTO-main.kicad_pcb, OTTO-main.sch, OTTO-power.kicad_pcb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]
2018-10-01 progresses in the mainboard wiring
    [OTTO-main.kicad_pcb, OTTO-main.sch, OTTO-power.kicad_pcb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]
2018-10-01 re-wired the stm32 to optimize the routing
    [OTTO-main.kicad_pcb, OTTO-main.sch]
